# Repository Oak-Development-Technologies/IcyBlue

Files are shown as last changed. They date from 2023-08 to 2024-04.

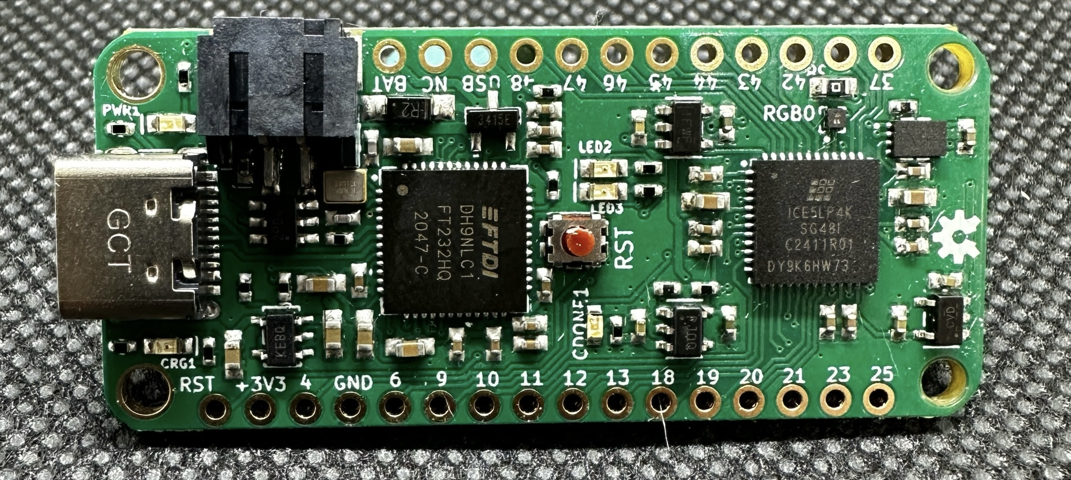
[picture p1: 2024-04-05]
Images/IMG_2196.jpg

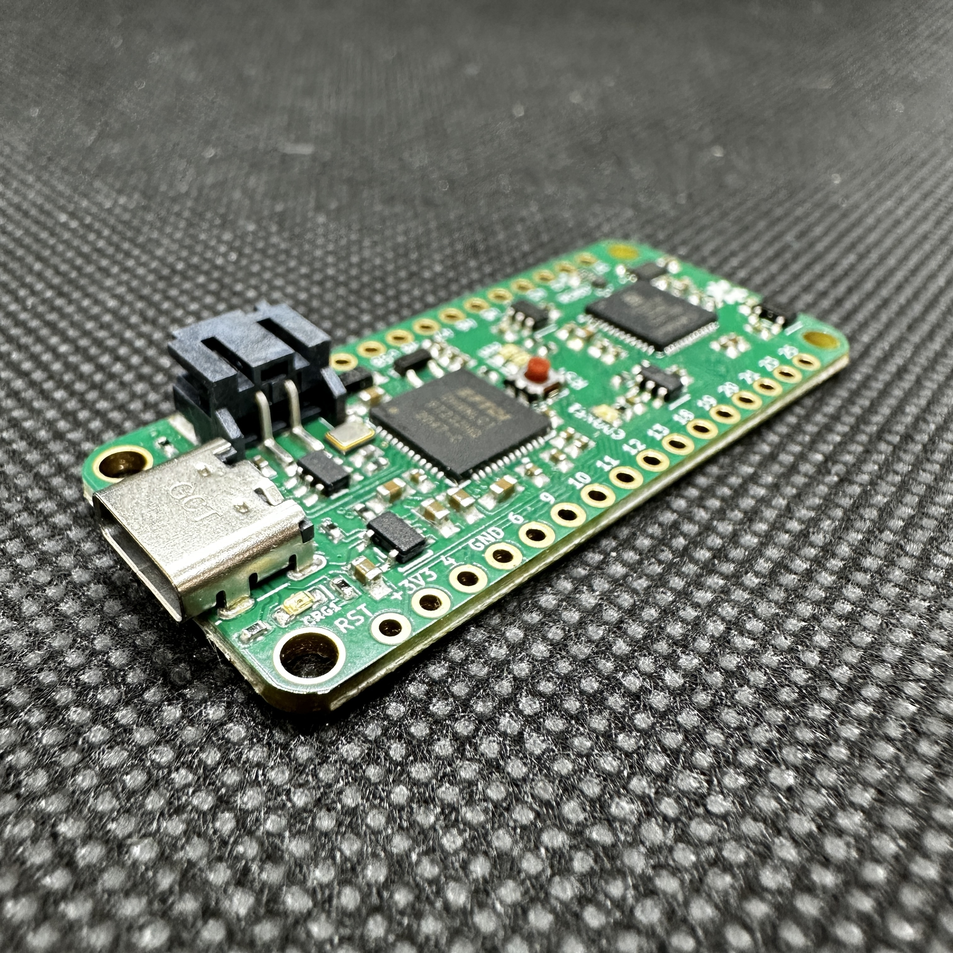
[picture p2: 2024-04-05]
Images/IMG_2199.jpg

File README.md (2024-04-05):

# IcyBlue Feather FPGA Development Board

<image src="https://github.com/Oak-Development-Technologies/IcyBlue/blob/main/Images/IMG_2196.jpg">

Welcome to the home of the IcyBlue Feather, an FPGA based development board designed to be integrated into the Adafruit Feather ecosystem of Feathers and Feather Wings.

The goal of this repository is to be the single source of truth for the IcyBlue Feather. Containing all the relevant articles including images, schematics, usage examples, board files, and other important documentation.

Questions? Email [hello@oakdev.tech](mailto:hello@oakdev.tech)

### Documentation ###

All documentation can be found under the [Documentation](https://github.com/Oak-Development-Technologies/IcyBlue/tree/main/Documentation) directory of this repository. This will include data sheets, usage guides, application notes, errata, and other important documents.

Documentation quick links:
* Data sheet: [IcyBlue Overview Data Sheet](https://github.com/Oak-Development-Technologies/IcyBlue/blob/main/Documentation/IcyBlue%20Feather%20V2%20Datasheet%20rev1a.docx)
* Board files: [EagleCAD Board Files](https://github.com/Oak-Development-Technologies/IcyBlue/blob/main/Documentation/Lattice%20FPGA%20standard%20feather%20wing.kicad_pcb)
* Schematic files: [EagleCAD Schematic Files](https://github.com/Oak-Development-Technologies/IcyBlue/blob/main/Documentation/Lattice%20FPGA%20standard%20feather%20wing.kicad_sch)

### Schematic ###

Represented below is the Rev 1a schematic. This is the current production schematic for the IcyBlue Feather. If major hardware changes are added, additional labeled schematic images can be found here and in the [documentation directory](https://github.com/Oak-Development-Technologies/IcyBlue/tree/main/Documentation).

<image src="https://github.com/Oak-Development-Technologies/IcyBlue/blob/main/Images/IcyBlue%20Schematic.png">

### Usage Examples ###

All usage examples including the RGB sequence example that ships with the board can be found in the [examples repository](https://github.com/skerr92/ice5lp4k_examples).

Examples Quick Links:
* [RGB Blink](https://github.com/skerr92/ice5lp4k_examples/tree/master/leds)
* [DSP Example](https://github.com/skerr92/ice5lp4k_examples/tree/master/dsp)
* [RGB Rainbow Chase](https://github.com/Oak-Development-Technologies/ice40_rgb_rainbow_chase)

### Errata ###

Any Errate for the IcyBlue Feather will be linked below with the specific dates and errata version.

### Additional Information ###

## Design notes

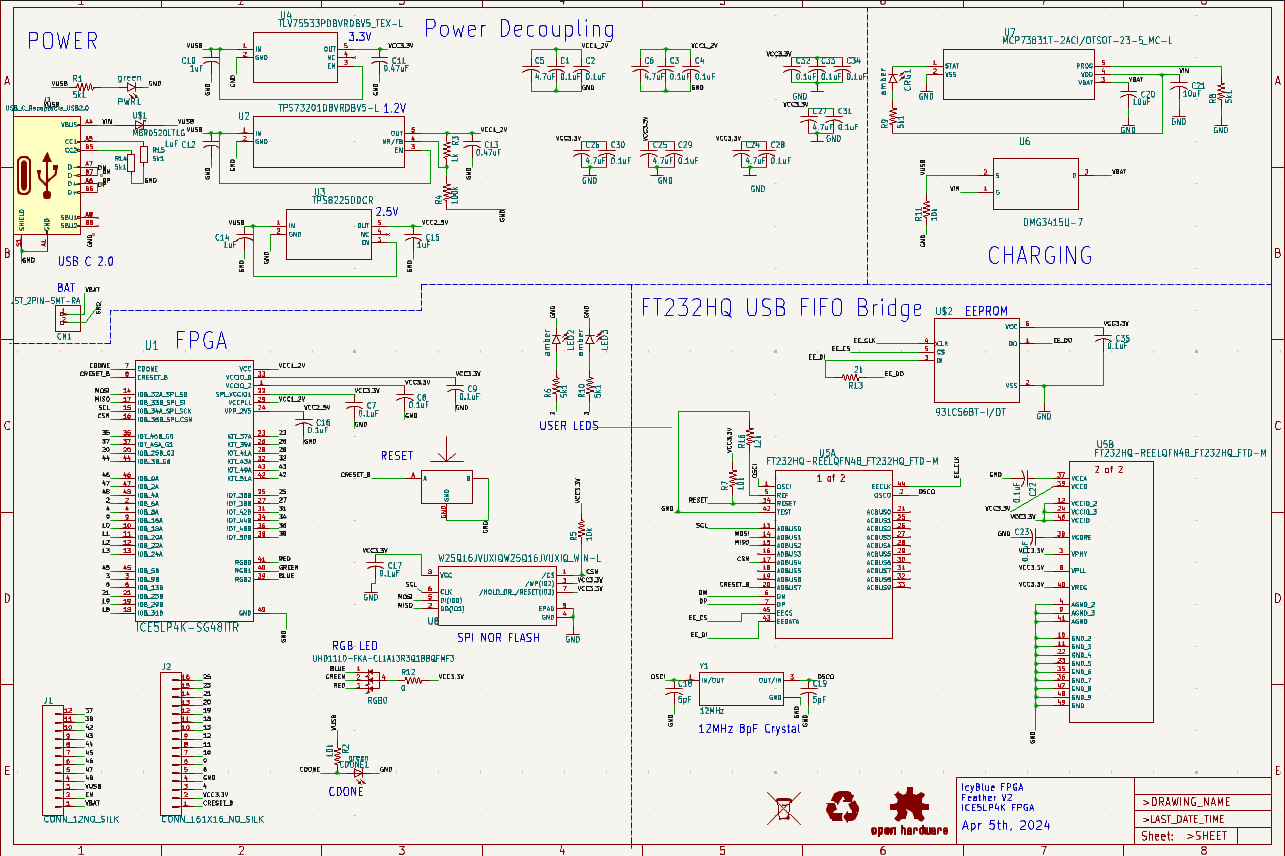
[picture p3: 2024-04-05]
Images/IcyBlue Schematic.png

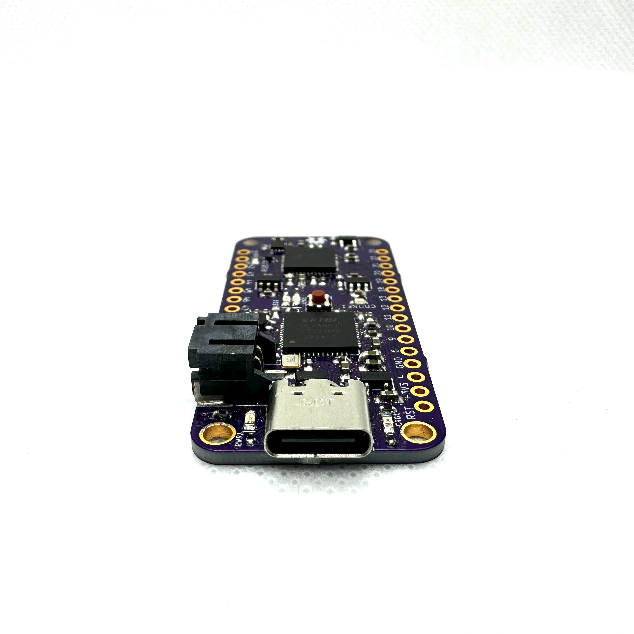
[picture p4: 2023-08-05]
Images/IcyBlue-Front-2.jpg

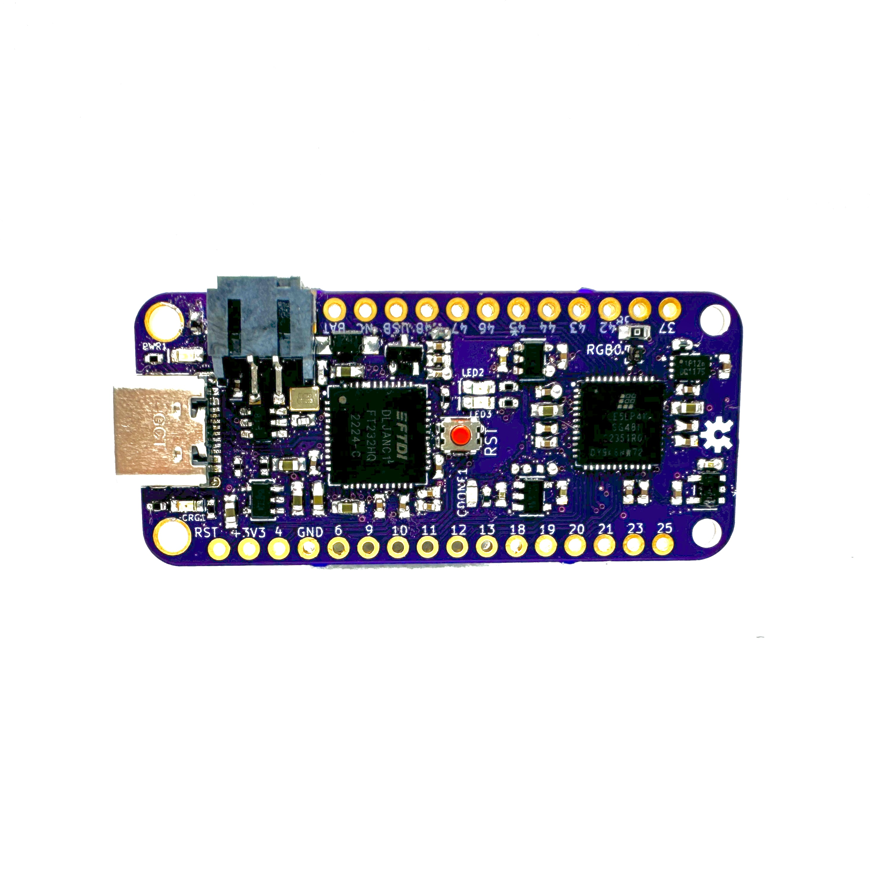
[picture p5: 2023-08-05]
Images/IcyBlue-Top-2.jpg

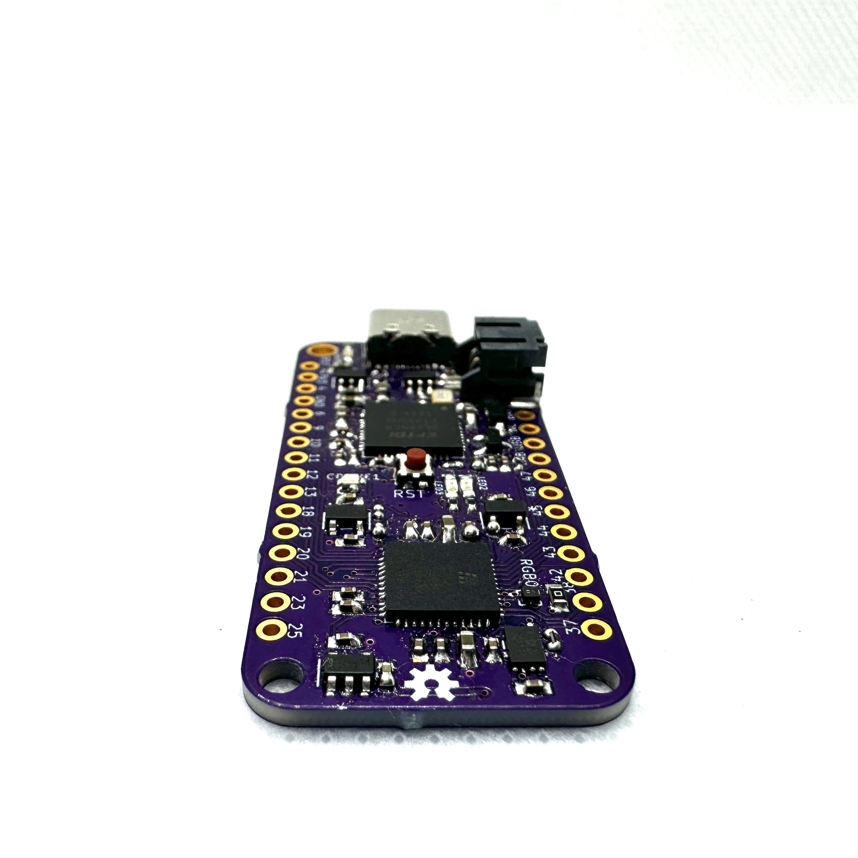
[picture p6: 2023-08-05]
Images/IcyBlue-Back-2.jpg

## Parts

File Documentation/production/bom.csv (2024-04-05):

Designator | Footprint | Quantity | Value | LCSC Part #
C1, C16, C17, C2, C22, C23, C28, C29, C3, C30, C31, C32, C33, C34, C35, C4, C7, C8, C9 | C0402 | 19 | 0.1uF
C10, C12, C14, C15 | C0402 | 4 | 1uF
C11, C13 | C0402 | 2 | 0.47uF
C18, C19 | C0402 | 2 | 5pF
C20, C21 | C0603 | 2 | 10uF
C24, C25, C26, C27, C5, C6 | C0603 | 6 | 4.7uF
CDONE1 | CHIP-LED0603 | 1 | green
CN1 | JST-PH-2-SMT-RA | 1 | JST_2PIN-SMT-RA
CRG1, LED2, LED3 | LED-0603 | 3 | amber
J1 | 1X12_NO_SILK | 1 | CONN_12NO_SILK
J2 | 1X16_NO_SILK | 1 | CONN_161X16_NO_SILK
J3 | USB_C_Receptacle_GCT_USB4105-xx-A_16P_TopMnt_Horizontal | 1 | USB_C_Receptacle_USB2.0
LOGO1 | OSHW-LOGO-S | 1 | OSHW-LOGOS
PWR1 | LED-0603 | 1 | green
R1, R10, R6, R8, R9 | R0402 | 5 | 5k1
R11, R2, R5, R7 | R0402 | 4 | 10k
R12 | R0603 | 1 | 0
R13 | R0402 | 1 | 2k
R14, R15 | 0402 | 2 | 5k1
R16 | R0402 | 1 | 12k
R3 | R0402 | 1 | 1k
R4 | R0402 | 1 | 100k
RGB0 | LED_UHD1110-FKA-CL1A13R3Q1BBQFMF3 | 1 | UHD1110-FKA-CL1A13R3Q1BBQFMF3
U$1 | SOD3716X117(SOD-123) | 1 | MBR0520LT1G
U$2 | SOT95P280X145-6N | 1 | 93LC56BT-I/OT
U$3 | 3.3X2.9 | 1 | SOF-232HST
U1 | QFN50P700X700X100-49N | 1 | ICE5LP4K-SG48ITR
U2 | DBV5-L | 1 | TPS73201DBVRDBV5-L
U3 | DBV5_TEX-L | 1 | TPS8225DDCR
U4 | DBV5_TEX-L | 1 | TLV75533PDBVRDBV5_TEX-L
U5 | QFN48_FT232HQ_FTD-M | 1 | FT232HQ-REELQFN48_FT232HQ_FTD-M
U6 | SOT95P240X105-3N | 1 | DMG3415U-7
U7 | SOT-23-5_MC-L | 1 | MCP73831T-2ACI/OTSOT-23-5_MC-L
U8 | W25Q16JVUXIQ_WIN-L | 1 | W25Q16JVUXIQW25Q16JVUXIQ_WIN-L
Y1 | XTAL_ECS-480-10-37-JTN-TR | 1 | 12MHz

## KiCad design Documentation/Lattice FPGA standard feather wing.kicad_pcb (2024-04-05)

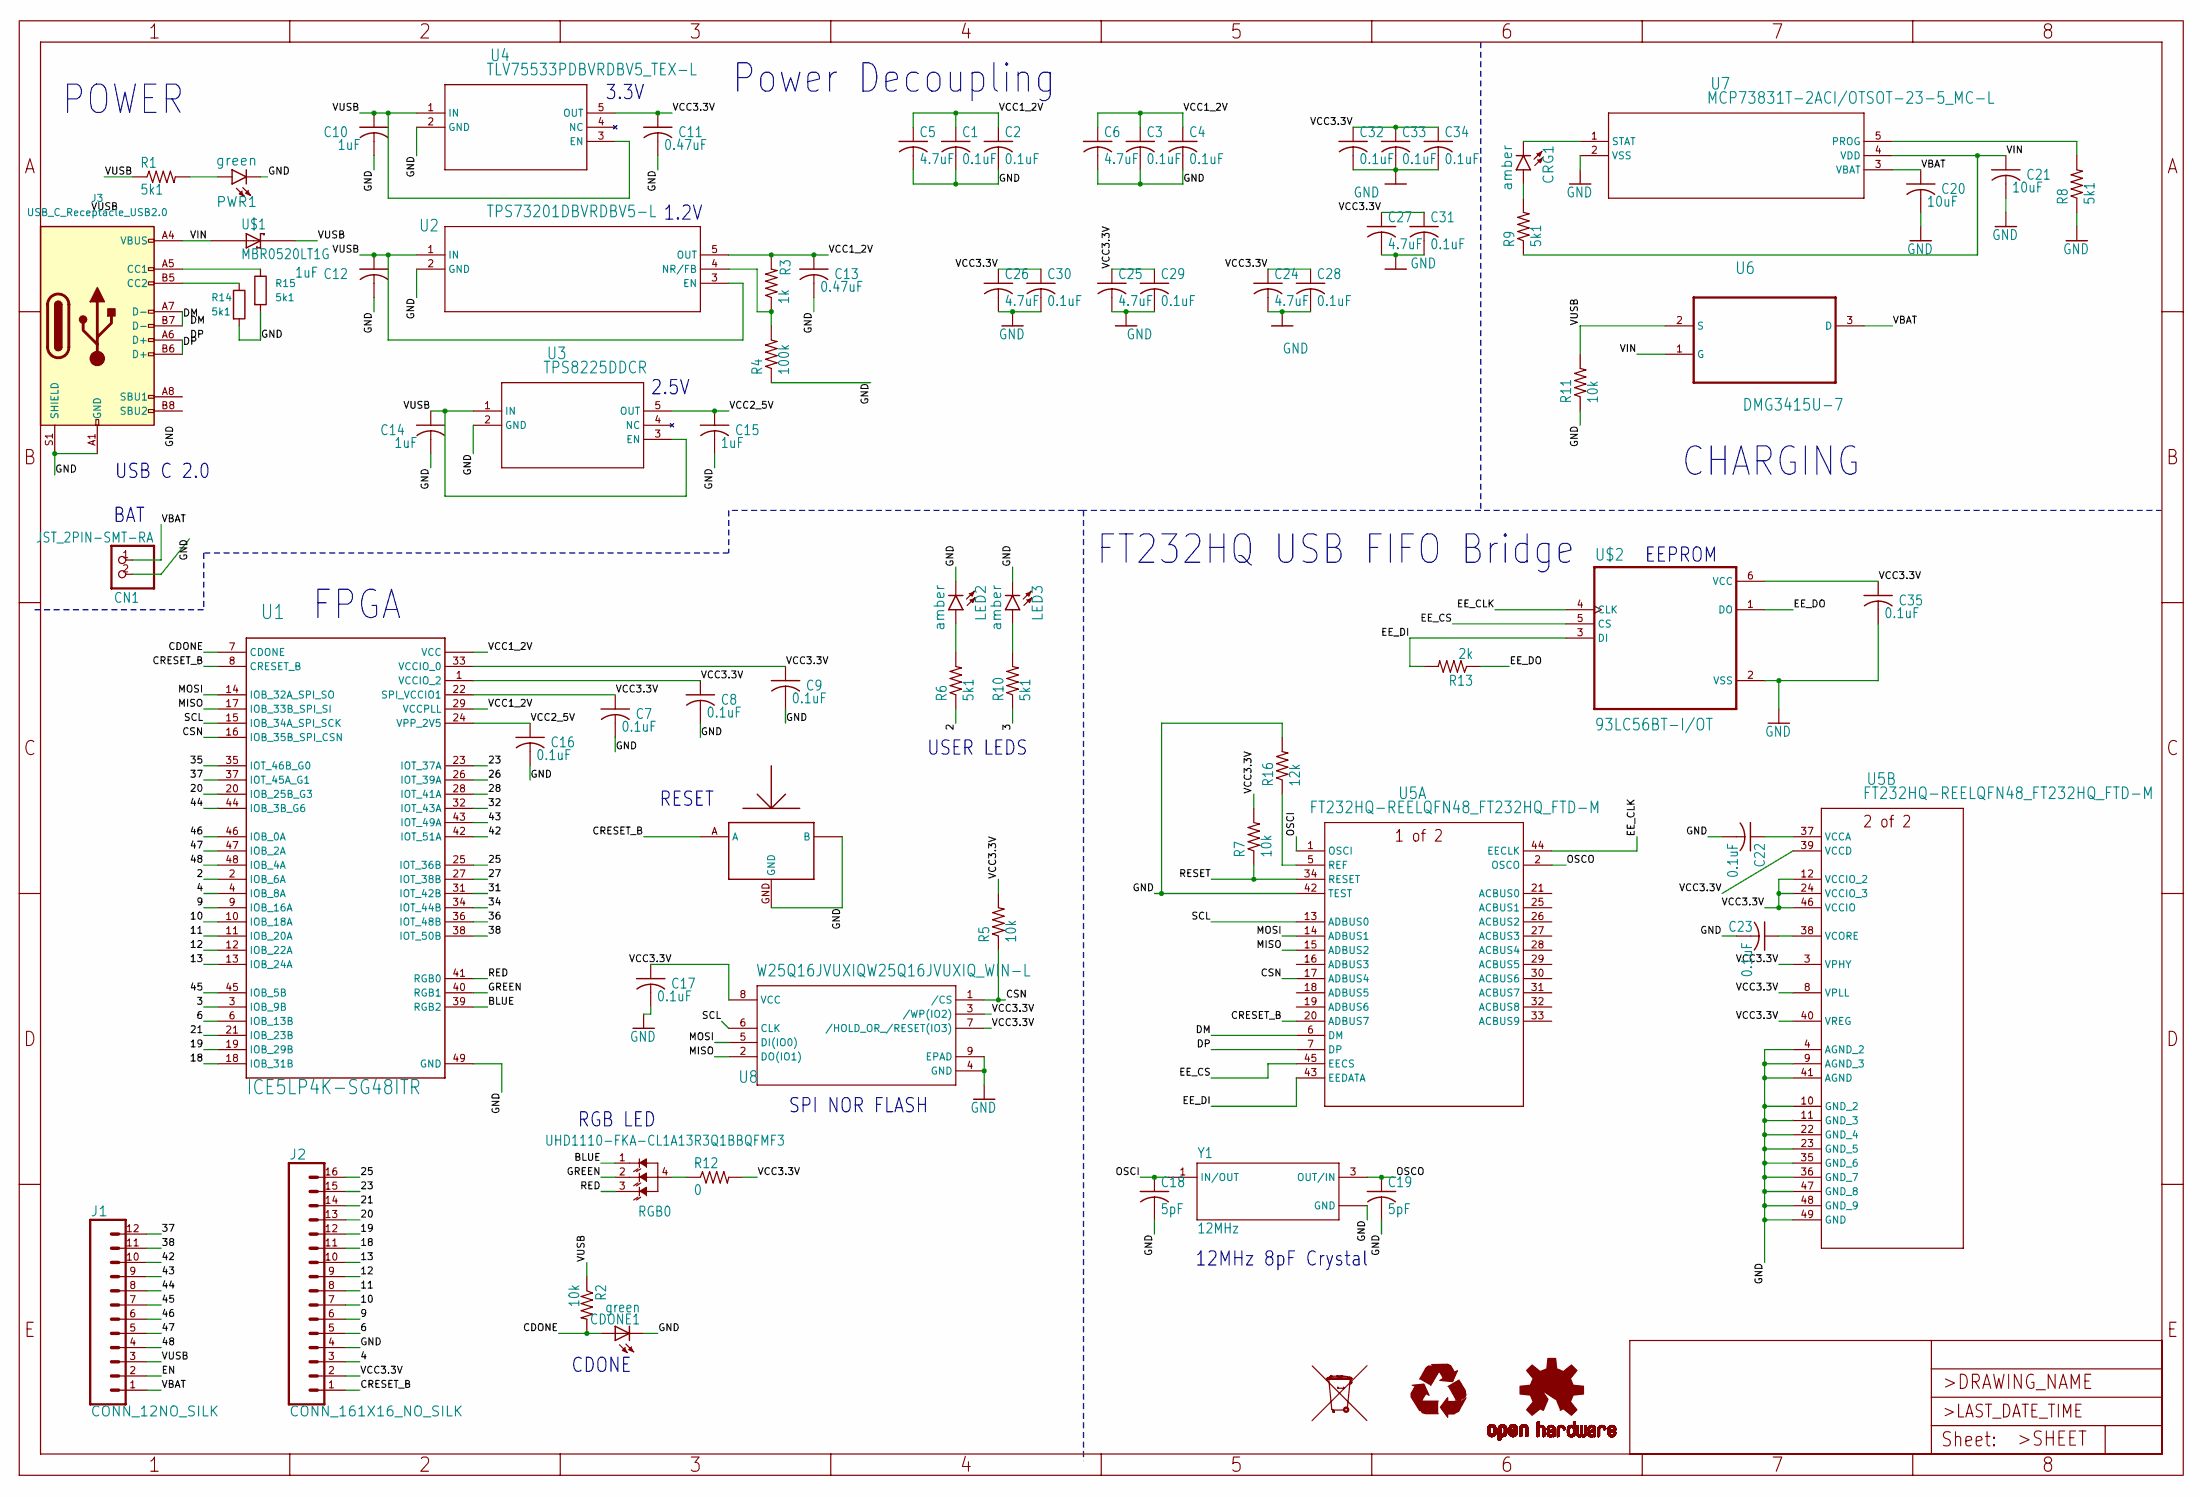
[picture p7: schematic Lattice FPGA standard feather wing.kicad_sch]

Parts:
C1, C2, C3, C4, C7, C8, C9, C16, C17, C22, C23, C28, C29, C30, C31, C32, C33, C34, C35: 0.1uF; C0402
C5, C6, C24, C25, C26, C27: 4.7uF; C0603
C10, C12, C14, C15: 1uF; C0402
C11, C13: 0.47uF; C0402
C18, C19: 5pF; C0402
C20, C21: 10uF; C0603
CDONE1: green; CHIP-LED0603
CN1: JST_2PIN-SMT-RA; JST-PH-2-SMT-RA
CRG1: amber; LED-0603
J1: CONN_12NO_SILK; 1X12_NO_SILK
J2: CONN_161X16_NO_SILK; 1X16_NO_SILK
J3: USB_C_Receptacle_USB2.0; USB_C_Receptacle_GCT_USB4105-xx-A_16P_TopMnt_Horizontal
LED2, LED3: amber; LED-0603
LOGO1: OSHW-LOGOS; OSHW-LOGO-S
PWR1: green; LED-0603
R1, R6, R8, R9, R10: 5k1; R0402
R2, R5, R7, R11: 10k; R0402
R3: 1k; R0402
R4: 100k; R0402
R12: 0; R0603
R13: 2k; R0402
R14, R15: 5k1; R_0402_1005Metric
R16: 12k; R0402
RGB0: UHD1110-FKA-CL1A13R3Q1BBQFMF3; LED_UHD1110-FKA-CL1A13R3Q1BBQFMF3
U1: ICE5LP4K-SG48ITR; QFN50P700X700X100-49N
U2: TPS73201DBVRDBV5-L; DBV5-L
U3: TPS8225DDCR; DBV5_TEX-L
U4: TLV75533PDBVRDBV5_TEX-L; DBV5_TEX-L
U5: FT232HQ-REELQFN48_FT232HQ_FTD-M; QFN48_FT232HQ_FTD-M
U6: DMG3415U-7; SOT95P240X105-3N
U7: MCP73831T-2ACI/OTSOT-23-5_MC-L; SOT-23-5_MC-L
U8: W25Q16JVUXIQW25Q16JVUXIQ_WIN-L; W25Q16JVUXIQ_WIN-L
U$1: MBR0520LT1G; SOD3716X117(SOD-123)
U$2: 93LC56BT-I/OT; SOT95P280X145-6N
U$3: SOF-232HST; 3.3X2.9
Y1: 12MHz; XTAL_ECS-480-10-37-JTN-TR

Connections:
/2: R6.1, U1.2 (IOB_6A)
/3: R10.1, U1.3 (IOB_9B)
/4: J2.3, U1.4 (IOB_8A)
/6: J2.5, U1.6 (IOB_13B)
/9: J2.6, U1.9 (IOB_16A)
/10: J2.7, U1.10 (IOB_18A)
/11: J2.8, U1.11 (IOB_20A)
/12: J2.9, U1.12 (IOB_22A)
/13: J2.10, U1.13 (IOB_24A)
/18: J2.11, U1.18 (IOB_31B)
/19: J2.12, U1.19 (IOB_29B)
/20: J2.13, U1.20 (IOB_25B_G3)
/21: J2.14, U1.21 (IOB_23B)
/23: J2.15, U1.23 (IOT_37A)
/25: J2.16, U1.25 (IOT_36B)
/26: U1.26 (IOT_39A)
/27: U1.27 (IOT_38B)
/28: U1.28 (IOT_41A)
/31: U1.31 (IOT_42B)
/32: U1.32 (IOT_43A)
/34: U1.34 (IOT_44B)
/35: U1.35 (IOT_46B_G0)
/36: U1.36 (IOT_48B)
/37: J1.12, U1.37 (IOT_45A_G1)
/38: J1.11, U1.38 (IOT_50B)
/42: J1.10, U1.42 (IOT_51A)
/43: J1.9, U1.43 (IOT_49A)
/44: J1.8, U1.44 (IOB_3B_G6)
/45: J1.7, U1.45 (IOB_5B)
/46: J1.6, U1.46 (IOB_0A)
/47: J1.5, U1.47 (IOB_2A)
/48: J1.4, U1.48 (IOB_4A)
/BLUE: RGB0.1 (BLUE), U1.39 (RGB2)
/CDONE: CDONE1.A, R2.2, U1.7 (CDONE)
/CRESET_B: J2.1, U1.8 (CRESET_B), U5.20 (ADBUS7), U$3.A
/CSN: R5.1, U1.16 (IOB_35B_SPI_CSN), U5.17 (ADBUS4), U8.1 (/CS)
/DM: J3.A7 (D-), J3.B7 (D-), U5.6 (DM)
/DP: J3.A6 (D+), J3.B6 (D+), U5.7 (DP)
/EE_CLK: U5.44 (EECLK), U$2.4 (CLK)
/EE_CS: U5.45 (EECS), U$2.5 (CS)
/EE_DI: R13.2, U5.43 (EEDATA), U$2.3 (DI)
/EE_DO: R13.1, U$2.1 (DO)
/EN: J1.2
/GREEN: RGB0.2 (GREEN), U1.40 (RGB1)
/MISO: U1.17 (IOB_33B_SPI_SI), U5.15 (ADBUS2), U8.2 (DO(IO1))
/MOSI: U1.14 (IOB_32A_SPI_SO), U5.14 (ADBUS1), U8.5 (DI(IO0))
/OSCI: C18.1, U5.1 (OSCI), Y1.1 (IN/OUT)
/OSCO: C19.1, U5.2 (OSCO), Y1.3 (OUT/IN)
/RED: RGB0.3 (RED), U1.41 (RGB0)
/RESET: R7.1, U5.34 (RESET)
/SCL: U1.15 (IOB_34A_SPI_SCK), U5.13 (ADBUS0), U8.6 (CLK)
/VBAT: C20.1, CN1.1 (2), J1.1, U6.3 (D), U7.3 (VBAT)
/VCC1_2V: C1.1, C2.1, C3.1, C4.1, C5.1, C6.1, C13.1, R3.2, U1.5 (VCC), U1.29 (VCCPLL), U1.30 (VCC), U2.5 (OUT)
/VCC2_5V: C15.1, C16.1, U1.24 (VPP_2V5), U3.5 (OUT)
/VCC3.3V: C7.1, C8.1, C9.1, C11.1, C17.1, C24.1, C25.1, C26.1, C27.1, C28.1, C29.1, C30.1, C31.1, C32.1, C33.1, C34.1, C35.1, J2.2, R5.2, R7.2, R12.2, U1.1 (VCCIO_2), U1.22 (SPI_VCCIO1), U1.33 (VCCIO_0), U4.5 (OUT), U5.3 (VPHY), U5.8 (VPLL), U5.12 (VCCIO_2), U5.24 (VCCIO_3), U5.39 (VCCD), U5.40 (VREG), U5.46 (VCCIO), U8.3 (/WP(IO2)), U8.7 (/HOLD_OR_/RESET(IO3)), U8.8 (VCC), U$2.6 (VCC)
/VIN: C21.1, J3.A4 (VBUS), J3.A9 (VBUS), J3.B4 (VBUS), J3.B9 (VBUS), R9.1, U6.1 (G), U7.4 (VDD), U$1.2 (A)
/VUSB: C10.1, C12.1, C14.1, J1.3, R1.1, R2.1, R11.2, U2.1 (IN), U2.3 (EN), U3.1 (IN), U3.3 (EN), U4.1 (IN), U4.3 (EN), U6.2 (S), U$1.1 (C)
GND: C1.2, C2.2, C3.2, C4.2, C5.2, C6.2, C7.2, C8.2, C9.2, C10.2, C11.2, C12.2, C13.2, C14.2, C15.2, C16.2, C17.2, C18.2, C19.2, C20.2, C21.2, C22.2, C23.2, C24.2, C25.2, C26.2, C27.2, C28.2, C29.2, C30.2, C31.2, C32.2, C33.2, C34.2, C35.2, CDONE1.C, CN1.2 (1), J2.4, J3.A1 (GND), J3.A12 (GND), J3.B1 (GND), J3.B12 (GND), J3.S1 (SHIELD), LED2.C, LED3.C, PWR1.C, R4.1, R8.1, R11.1, R14.2, R15.2, R16.2, U1.49 (GND), U2.2 (GND), U3.2 (GND), U4.2 (GND), U5.4 (AGND_2), U5.9 (AGND_3), U5.10 (GND_2), U5.11 (GND_3), U5.22 (GND_4), U5.23 (GND_5), U5.35 (GND_6), U5.36 (GND_7), U5.41 (AGND), U5.42 (TEST), U5.47 (GND_8), U5.48 (GND_9), U5.49 (GND), U7.2 (VSS), U8.4 (GND), U8.9 (EPAD), U$2.2 (VSS), U$3.B, U$3.B2 (B), U$3.B3 (B), U$3.GND, Y1.2 (GND), Y1.4 (GND)
unnamed: CRG1.A, R9.2
unnamed: J3.A5 (CC1), R15.1
unnamed: J3.B5 (CC2), R14.1
unnamed: LED2.A, R6.2
unnamed: LED3.A, R10.2
unnamed: PWR1.A, R1.2
unnamed: R12.1, RGB0.4 (ANODE)
unnamed: R3.1, R4.2, U2.4 (NR/FB)
unnamed: R16.1, U5.5 (REF)
unnamed: C22.1, U5.37 (VCCA)
unnamed: C23.1, U5.38 (VCORE)
unnamed: R8.2, U7.5 (PROG)
unnamed: CRG1.C, U7.1 (STAT)

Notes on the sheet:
CHARGING
FPGA
RGB LED
3.3V
SPI NOR FLASH
1.2V
2.5V
BAT
EEPROM
RESET
CDONE
USER LEDS
POWER
FT232HQ USB FIFO Bridge
Power Decoupling
12MHz 8pF Crystal
USB C 2.0

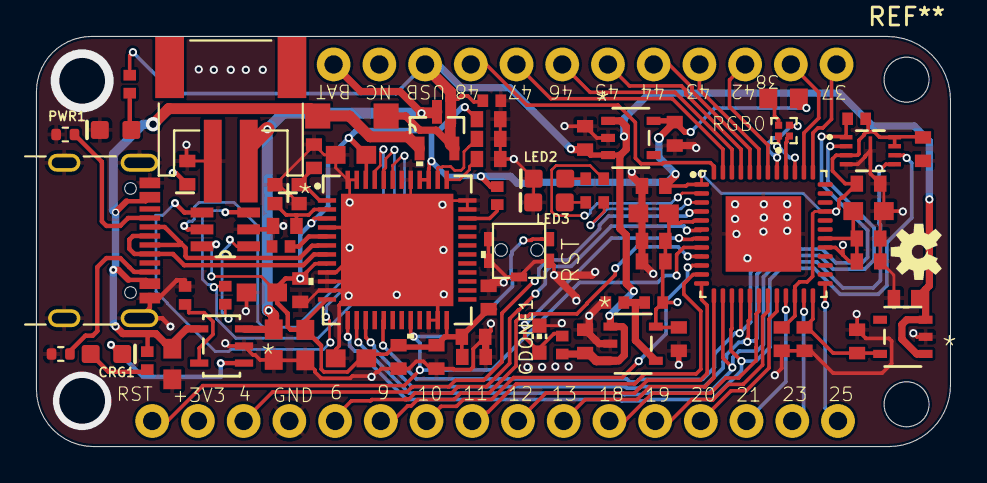
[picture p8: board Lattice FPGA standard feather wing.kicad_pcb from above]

Board: 4 copper layers, 50.8 x 22.8 mm, 74 parts (0 on the bottom side), 62 nets.

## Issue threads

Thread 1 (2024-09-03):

A few questions and suggestions

zapta, 2024-09-03:
Hello, I found this nice board from your submission to apio and have a few random questions and notes for your consideration.

1. Is the 12Mhz oscilator connected to the FPGA?  If not, it may be useful.
2. The FPGA datasheet mentions power rail sequencing. Have you considered it?
3. You can add a few examples at https://github.com/FPGAwars/apio-examples .  This way, apio users can run them using the apio examples command.
4. Have you considered adding here instructions for installing apio and running a simple hello world?

skerr92, 2024-09-08:
Hi there,

To answer your questions:

1. The distance between the 12MHz oscillator and the closest available FPGA pin is a bit far so connecting it might be troublesome. Given the board only goes up to 48MHz (which is difficult to achieve with complex designs), the onboard HFOSC and LFOSC are probably more than sufficient.

2. Power up sequencing has never been an issue on this board. The recommendations are likely based on the assumption that the FPGA will be incorporated on board with more demanding power schemes. That isn't the case here.

3. I can probably add examples, though I can give no time frame on when that will happen. Oak Development Technologies as a business has been shut down so there is no formal entity backing or selling this board anymore.

4. Same with the third response, some instructions can be added for using APIO, but I guarantee no time frame right now.

Thanks!
-Seth

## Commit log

2024-04-05 add new schematics, JLCPCB manufacturing files etc
    [Lattice FPGA standard feather wing.kicad_pcb, Lattice FPGA standard feather wing.kicad_sch, bom.csv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]
2024-04-05 add schematic picture
